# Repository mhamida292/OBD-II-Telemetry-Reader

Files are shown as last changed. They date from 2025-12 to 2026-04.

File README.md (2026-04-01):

# OBD-II Telemetry Reader

An OBD-II telemetry reader built with an ESP32 and designed in KiCAD.

## Overview

This project reads vehicle diagnostic data from the OBD-II port and displays it either on an LCD screen or streams it wirelessly via Bluetooth.

## Hardware

- **Microcontroller**: ESP32-S3 Rev 2
- **Design Software**: KiCAD 9
- **Input**: OBD-II connector (standard 16-pin)
- **Output Options**:
  - OLED display (I2C interface)
  - Bluetooth serial communication

## Features

- Real-time vehicle data monitoring
- Multiple data parameter support (RPM, speed, temperature, etc.)
- Wireless data transmission via Bluetooth
- Compact PCB design for automotive environment

## Future Enhancements

- WiFi data logging
- Mobile app integration
- Additional sensor support
- Data visualization dashboard

---

Built as a personal project.

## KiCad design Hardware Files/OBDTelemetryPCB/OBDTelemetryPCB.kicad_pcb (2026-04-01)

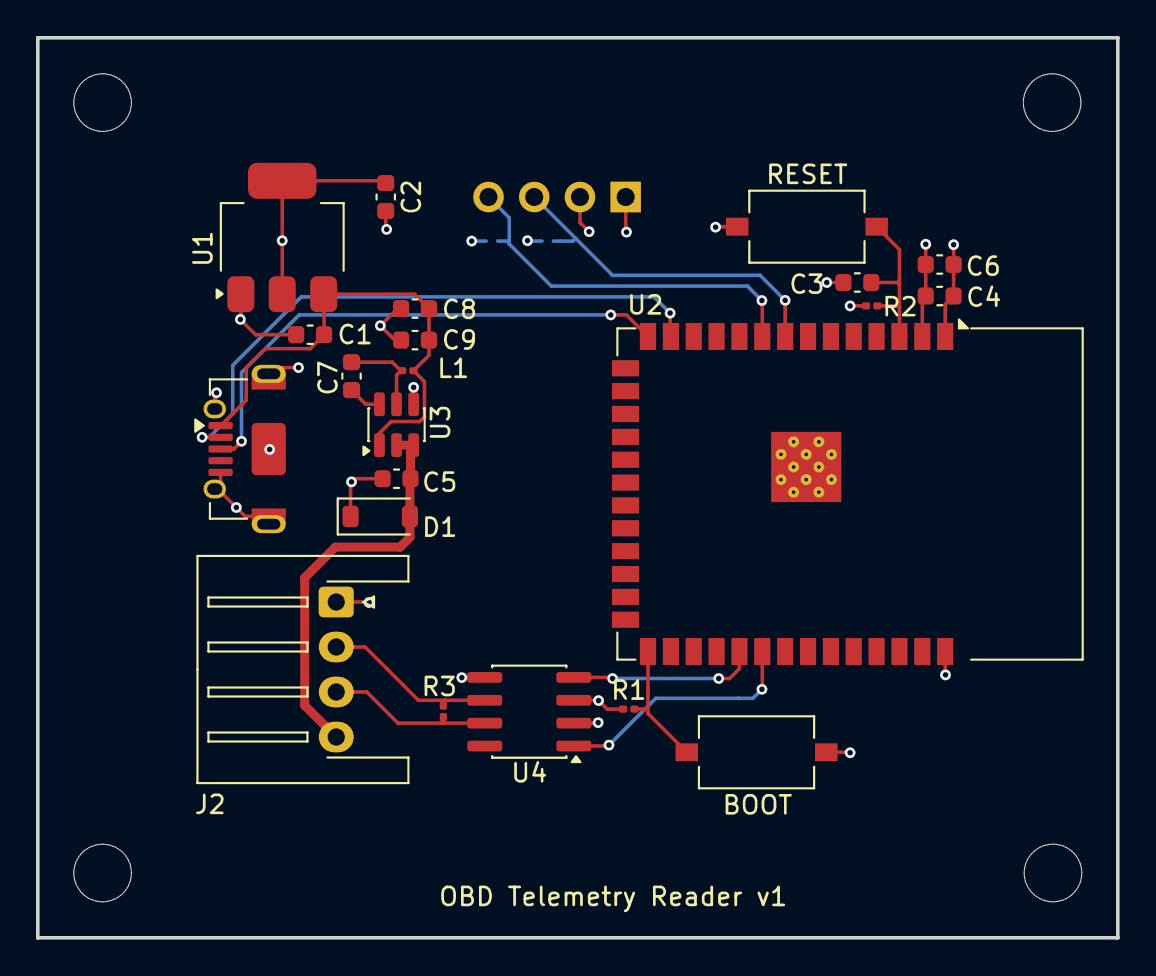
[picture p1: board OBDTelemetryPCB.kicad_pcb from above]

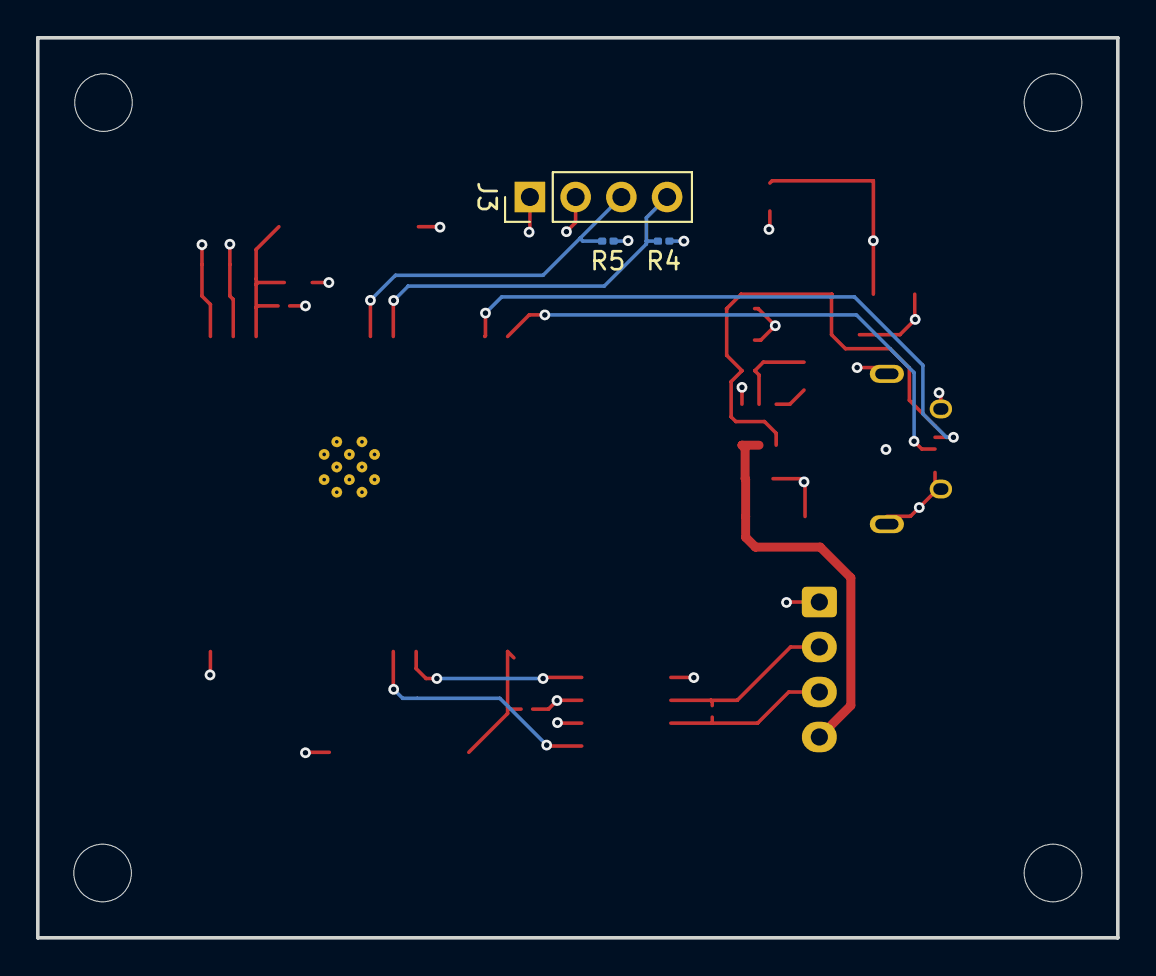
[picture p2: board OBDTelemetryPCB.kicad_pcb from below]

Board: 4 copper layers, 60.0 x 50.0 mm, 25 parts (3 on the bottom side), 16 nets.

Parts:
C1, C3: 1uF; C_0603_1608Metric
C2: 2.2uF; C_0603_1608Metric
C4: 0.1uF; C_0603_1608Metric
C5, C6: 10uF; C_0603_1608Metric
C7: 100nF; C_0603_1608Metric
C8, C9: 22uF; C_0603_1608Metric
D1: SM6T15A; D_SOD-123
J1: USB_B_Micro; USB_Micro-AB_Molex_47590-0001
J2: InputSocket; JST_XH_S4B-XH-A-1_1x04_P2.50mm_Horizontal
J3: Conn_01x04_Socket; PinHeader_1x04_P2.54mm_Vertical
L1: 4.7uH; R_0201_0603Metric
R1, R2: 10k; R_0201_0603Metric
R3: 120; R_0201_0603Metric
R4, R5: 4.7k; R_0201_0603Metric
SW1: BOOT; SW_Tactile_SPST_NO_Straight_CK_PTS636Sx25SMTRLFS
SW2: RESET; SW_Tactile_SPST_NO_Straight_CK_PTS636Sx25SMTRLFS
U1: TLV76133DCY; SOT-223-3_TabPin2
U2: ESP32-S3-WROOM-1
U3: AP63205WU; TSOT-23-6
U4: SN65HVD230; SOIC-8_3.9x4.9mm_P1.27mm

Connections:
+3.3V: C2.1, C4.1, C6.1, J3.2, R1.1, R2.1, R4.2, R5.2, U1.2 (VO), U2.2 (3V3), U4.3 (VCC)
+5V: C1.1, C8.2, C9.2, J1.1 (VBUS), L1.2, U1.3 (VI), U3.1 (FB)
+12V: C5.1, D1.2 (A2), J2.4, U3.2 (EN), U3.3 (IN)
/BOOT: R1.2, SW1.2, U2.27 (IO0)
/CANH: J2.3, R3.2, U4.7 (CANH)
/CANL: J2.2, R3.1, U4.6 (CANL)
/D+: J1.3 (D+), U2.14 (USB_D+)
/D-: J1.2 (D-), U2.13 (USB_D-)
/DTX: U2.32 (IO39), U4.1 (D)
/EN: C3.2, R2.2, SW2.2, U2.3 (EN)
/RTX: U2.31 (IO38), U4.4 (R)
/SCL: J3.3, R5.1, U2.8 (IO15)
/SDA: J3.4, R4.1, U2.9 (IO16)
GND: C1.2, C2.2, C3.1, C4.2, C5.2, C6.2, C8.1, C9.1, D1.1 (A1), J1.5 (GND), J1.6 (Shield), J2.1, J3.1, SW1.1, SW2.1, U1.1 (GND), U2.1 (GND), U2.40 (GND), U2.41 (GND), U3.4 (GND), U4.2 (GND), U4.5 (Vref)
unnamed: C7.2, U3.6 (BST)
unnamed: C7.1, L1.1, U3.5 (SW)

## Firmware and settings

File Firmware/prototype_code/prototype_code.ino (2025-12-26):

// ESP32 + SN65HVD230
// OBD-II Fuel Level (Mode 01, PID 0x2F)
// Pins: TX=GPIO22, RX=GPIO23
// Connect to OBD-II: CANH=pin 6, CANL=pin 14, GND=pin 4/5

#include "driver/twai.h"

#define RX_PIN 23
#define TX_PIN 22

void setup() {
  Serial.begin(115200);

  // TWAI init: NORMAL mode @ 500 kbps
  twai_general_config_t g =
      TWAI_GENERAL_CONFIG_DEFAULT((gpio_num_t)TX_PIN, (gpio_num_t)RX_PIN, TWAI_MODE_NORMAL);
  twai_timing_config_t  t = TWAI_TIMING_CONFIG_500KBITS();
  twai_filter_config_t  f = TWAI_FILTER_CONFIG_ACCEPT_ALL();

  if (twai_driver_install(&g, &t, &f) != ESP_OK || twai_start() != ESP_OK) {
    Serial.println("TWAI init failed");
    while (1) {}
  }

  Serial.println("OBD-II Fuel Level (PID 0x2F) reader started...");
}

void loop() {
  // Build functional request frame: ID 0x7DF, data = 02 01 2F 00 00 00 00 00
  twai_message_t tx = {};
  tx.identifier = 0x7DF;
  tx.extd = 0; tx.rtr = 0; tx.data_length_code = 8;
  tx.data[0] = 0x02;   // 2 more bytes (01, 2F)
  tx.data[1] = 0x01;   // Mode 01: current data
  tx.data[2] = 0x2F;   // PID 0x2F = Fuel Level
  for (int i = 3; i < 8; i++) tx.data[i] = 0;

  if (twai_transmit(&tx, pdMS_TO_TICKS(100)) != ESP_OK) {
    Serial.println("TX failed");
  }

  // Wait up to 800 ms for reply
  bool got = false;
  uint32_t t0 = millis();
  while (millis() - t0 < 800) {
    twai_message_t rx;
    if (twai_receive(&rx, pdMS_TO_TICKS(50)) == ESP_OK) {
      if (!rx.extd && !rx.rtr &&
          rx.identifier >= 0x7E8 && rx.identifier <= 0x7EF &&
          rx.data_length_code >= 4 &&
          rx.data[1] == 0x41 && rx.data[2] == 0x2F) {

        uint8_t raw = rx.data[3];              // single byte
        float fuel_pct = (raw * 100.0f) / 255.0f;
        Serial.printf("Fuel Level: %.1f%% (raw=0x%02X from ID 0x%03lX)\n",
                      fuel_pct, raw, rx.identifier);
        got = true;
        break;
      }
    }
  }

  if (!got) {
    Serial.println("No reply for Fuel Level (PID 0x2F) — may not be supported.");
  }

  delay(2000); // poll every 2s
}

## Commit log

2025-12-26 V0.1 - Save Point
    [OBDTelemetryPCB.kicad_pcb, OBDTelemetryPCB.kicad_sch]
2025-12-27 Updated PCB
    [OBDTelemetryPCB.kicad_pcb, OBDTelemetryPCB.kicad_sch]
2026-04-01 Completed v1 of hardware
    [OBDTelemetryPCB-B_Cu.gbr, OBDTelemetryPCB-B_Mask.gbr, OBDTelemetryPCB-B_Paste.gbr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]
